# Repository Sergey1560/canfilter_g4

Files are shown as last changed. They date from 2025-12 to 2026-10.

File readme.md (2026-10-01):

# CAN Filter

[Схема платы](./canfilter_g4.pdf)

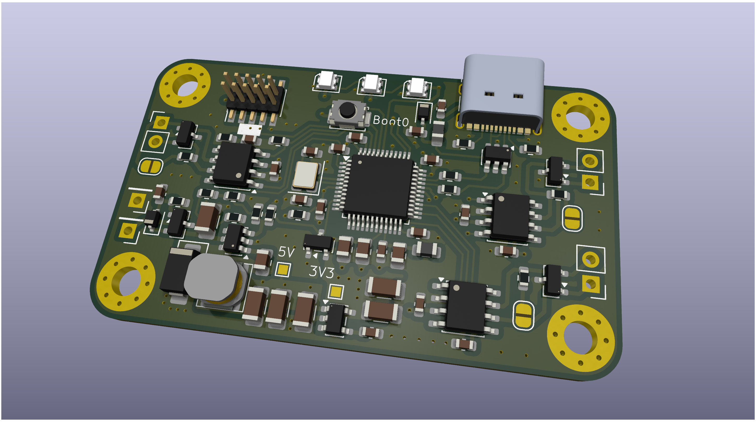
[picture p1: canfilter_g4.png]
top


# Примеры кода

- [AEM2ABIT](https://github.com/Sergey1560/canfilter_aem2abit) конвертирует сообщения от ШДК AEM в формат ADLM ABIT
- [SOCKET_CAN](https://github.com/Sergey1560/canfilter_socketcan_sw) USB адаптер для Linux с 3-мя интерфейсами CAN

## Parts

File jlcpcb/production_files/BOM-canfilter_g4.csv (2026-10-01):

Comment | Designator | Footprint | LCSC | Quantity
0.1uF | C108,C109,C111,C113,C114,C116,C301,C302,C401,C402,C501,C502,C601,C602 | C_0603_1608Metric | C14663 | 14
0.1uF | C112,C202 | C_0805_2012Metric | C49678 | 2
100K | R104,R106,R201 | R_0603_1608Metric | C25803 | 3
10K | R101,R102,R105,R203 | R_0603_1608Metric | C25804 | 4
10nF | C102,C103 | C_0603_1608Metric | C57112 | 2
10uF | C101,C104,C107,C201,C203,C204 | C_1206_3216Metric | C13585 | 6
120 | R301,R401,R501 | R_0603_1608Metric | C22787 | 3
12pF | C105,C106 | C_0603_1608Metric | C38523 | 2
1N4148WS | D107 | D_SOD-323 | C2128 | 1
1uF | C110,C115 | C_0805_2012Metric | C28323 | 2
22uH | L201 | FNR5040S220MT | C167971 | 1
27 | R603,R604 | R_0603_1608Metric | C25190 | 2
2K | R103 | R_0603_1608Metric | C22975 | 1
5.1K | R601,R602 | R_0603_1608Metric | C23186 | 2
54.9K | R202 | R_0603_1608Metric | C728593 | 1
8Mhz | Y101 | Crystal_SMD_3225-4Pin_3.2x2.5mm | C2682775 | 1
AO3401A | Q101 | SOT-23 | C15127 | 1
BAT54S | D105 | SOT-23 | C83935 | 1
BLM21BD471SN1D | L101 | L_0805_2012Metric | C2844596 | 1
BLM21PG221SN1D | FB601 | L_0805_2012Metric | C85840 | 1
BOOT0 | SW101 | SW_Push_SPST_NO_Alps_SKRK | C115357 | 1
BZT52C16S | D101 | D_SOD-323 | C19077449 | 1
LMR16006Y | U201 | SOT-23-6 | C290195 | 1
LP2985-3.3 | U101 | SOT-23-5 | C95414 | 1
NUP2105L | D301,D401,D501 | SOT-23 | C14486 | 3
SS14FL | D202 | D_SMA | C111580 | 1
STM32G474CBTx | U102 | LQFP-48_7x7mm_P0.5mm | C730123 | 1
SWD | J106 | PinHeader_2x05_P1.27mm_Vertical_SMD | C42372555 | 1
TJA1051T-3 | U301,U401,U501 | SOIC-8_3.9x4.9mm_P1.27mm | C3234095 | 3
USBLC6-2SC6 | U601 | SOT-23-6 | C7519 | 1
USB_C_Receptacle_USB2.0 | J601 | USB_C_Receptacle_XKB_U262-16XN-4BVC11 | C319148 | 1
WS2812B-2020 | D102,D104,D106 | LED_WS2812B-2020_PLCC4_2.0x2.0mm | C965555 | 3

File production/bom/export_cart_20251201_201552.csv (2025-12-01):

Index | LCSC# | MPN | Manufacturer | Package | Customer # | Description | RoHS | Quantity | MOQ | Multiple | Unit Price($) | Extended Price($) | Product Link
1 | C42372555 | HX JN1.27-2x5 TP H4.9 | hanxia | SMD,P=1.27mm | 34 | 1.27mm -40℃~+105℃ 1A Gold Copper 500V 2x5P 5 2 IDC Header 1.27mm Surface Mount,Vertical SMD,P=1.27mm Free Hanging, Panel Mount RoHS | yes | 10 | 5 | 5 | 0.2072 | 2.07 | https://www.lcsc.com/product-detail/C42372555.html
2 | C41376037 | HX PZ1.27-2x5P TP | hanxia | SMD,P=1.27mm | 34 | 10P 2x5P Gold Brass -40℃~+105℃ Pin Header Black 1.27mm 1mm 4mm 500V 2 1A Surface Mount,Vertical 1.27mm SMD,P=1.27mm Headers, Male Pins RoHS | yes | 10 | 5 | 5 | 0.0831 | 0.83 | https://www.lcsc.com/product-detail/C41376037.html
3 | C730123 | STM32G474CBT6 | ST | LQFP-48(7x7) | 24 | ARM Cortex-M4F 170MHz 38 LQFP-48(7x7) Microcontrollers RoHS | yes | 10 | 1 | 1 | 3.4997 | 35.00 | https://www.lcsc.com/product-detail/C730123.html
4 | C14663 | CC0603KRX7R9BB104 | YAGEO | 0603 | 1 | 50V 100nF X7R ±10% 0603 Ceramic Capacitors RoHS | yes | 200 | 100 | 100 | 0.0025 | 0.50 | https://www.lcsc.com/product-detail/C14663.html
5 | C89632 | CL31B106KBHNNNE | Samsung Electro-Mechanics | 1206 | 2 | 50V 10uF X7R ±10% 1206 Ceramic Capacitors RoHS | yes | 60 | 10 | 10 | 0.0557 | 3.34 | https://www.lcsc.com/product-detail/C89632.html
6 | C100042 | CC0603KRX7R9BB103 | YAGEO | 0603 | 3 | 50V 10nF X7R ±10% 0603 Ceramic Capacitors RoHS | yes | 100 | 100 | 100 | 0.0022 | 0.22 | https://www.lcsc.com/product-detail/C100042.html
7 | C38523 | CL10C120JB8NNNC | Samsung Electro-Mechanics | 0603 | 4 | 50V 12pF C0G ±5% 0603 Ceramic Capacitors RoHS | yes | 100 | 100 | 100 | 0.0049 | 0.49 | https://www.lcsc.com/product-detail/C38523.html
8 | C77083 | GRM21BR71H105KA12L | muRata | 0805 | 5 | 50V 1uF X7R ±10% 0805 Ceramic Capacitors RoHS | yes | 20 | 20 | 20 | 0.0366 | 0.73 | https://www.lcsc.com/product-detail/C77083.html
9 | C49678 | CC0805KRX7R9BB104 | YAGEO | 0805 | 6 | 50V 100nF X7R ±10% 0805 Ceramic Capacitors RoHS | yes | 100 | 100 | 100 | 0.0045 | 0.45 | https://www.lcsc.com/product-detail/C49678.html
10 | C319148 | U262-161N-4BVC11 | XKB Connection | SMD |  | 1 16P -40℃~+85℃ Type-C SMD USB, DVI, HDMI Connector Assemblies RoHS | yes | 15 | 5 | 5 | 0.3204 | 4.81 | https://www.lcsc.com/product-detail/C319148.html
11 | C98220 | RC0603FR-0710KL | YAGEO | 0603 | 7 | 100mW 10kΩ 75V ±100ppm/℃ Thick Film Resistor ±1% 0603 Chip Resistor - Surface Mount RoHS | yes | 100 | 100 | 100 | 0.0011 | 0.11 | https://www.lcsc.com/product-detail/C98220.html
12 | C14675 | RC0603FR-07100KL | YAGEO | 0603 | 8 | 100mW 100kΩ 75V ±100ppm/℃ Thick Film Resistor ±1% 0603 Chip Resistor - Surface Mount RoHS | yes | 100 | 100 | 100 | 0.0010 | 0.10 | https://www.lcsc.com/product-detail/C14675.html
13 | C22787 | 0603WAF1200T5E | UNI-ROYAL | 0603 | 9 | 100mW 120Ω 75V ±100ppm/℃ Thick Film Resistor ±1% 0603 Chip Resistor - Surface Mount RoHS | yes | 100 | 100 | 100 | 0.0012 | 0.12 | https://www.lcsc.com/product-detail/C22787.html
14 | C2907044 | FRC0603F5101TS | FOJAN | 0603 | 10 | 100mW 5.1kΩ 75V ±100ppm/℃ Thick Film Resistor ±1% 0603 Chip Resistor - Surface Mount RoHS | yes | 100 | 100 | 100 | 0.0009 | 0.09 | https://www.lcsc.com/product-detail/C2907044.html
15 | C25190 | 0603WAF270JT5E | UNI-ROYAL | 0603 | 11 | 100mW 27Ω 75V ±200ppm/℃ Thick Film Resistor ±1% 0603 Chip Resistor - Surface Mount RoHS | yes | 100 | 100 | 100 | 0.0012 | 0.12 | https://www.lcsc.com/product-detail/C25190.html
16 | C22975 | 0603WAF2001T5E | UNI-ROYAL | 0603 | 12 | 100mW 2kΩ 75V ±100ppm/℃ Thick Film Resistor ±1% 0603 Chip Resistor - Surface Mount RoHS | yes | 100 | 100 | 100 | 0.0011 | 0.11 | https://www.lcsc.com/product-detail/C22975.html
17 | C2999457 | FRC0603F5492TS | FOJAN | 0603 | 13 | 100mW 54.9kΩ 75V ±100ppm/℃ Thick Film Resistor ±1% 0603 Chip Resistor - Surface Mount RoHS | yes | 100 | 100 | 100 | 0.0009 | 0.09 | https://www.lcsc.com/product-detail/C2999457.html
18 | C710507 | BLM21BD471SN1D | muRata | 0805 | 14 | 350mΩ ±25% 470Ω@100MHz 0805 Ferrite Beads and Chips RoHS | yes | 20 | 10 | 10 | 0.0571 | 1.14 | https://www.lcsc.com/product-detail/C710507.html
19 | C167971 | FNR5040S220MT | cjiang | SMD,5x5mm | 15 | 22uH Magnetic Shielded Inductor 1.8A SMD,5x5mm Fixed Inductors RoHS | yes | 20 | 10 | 10 | 0.0933 | 1.87 | https://www.lcsc.com/product-detail/C167971.html
20 | C965555 | WS2812B-2020 | Worldsemi | SMD,2.2x2mm | 16 | SMD,2.2x2mm LED Addressable, Specialty RoHS | yes | 50 | 5 | 5 | 0.0658 | 3.29 | https://www.lcsc.com/product-detail/C965555.html
21 | C284104 | NUP2105L | DOWO | SOT-23 | 17 | 8A 420W@8/20us 43V 26.7V Bidirectional 24V SOT-23 TVS Diodes RoHS | yes | 30 | 10 | 10 | 0.0478 | 1.43 | https://www.lcsc.com/product-detail/C284104.html
22 | C19077449 | BZT52C16S | R+O | SOD-323 | 18 | Independent 200mW 15.3V~17.1V 16V SOD-323 Single Zener Diodes RoHS | yes | 50 | 50 | 50 | 0.0155 | 0.78 | https://www.lcsc.com/product-detail/C19077449.html
23 | C47546 | BAT54S,215 | Nexperia | SOT-23 | 19 | 600mA 1 Pair Series Connection 30V 800mV@100mA 200mA SOT-23 Single Diodes RoHS | yes | 30 | 5 | 5 | 0.0883 | 2.65 | https://www.lcsc.com/product-detail/C47546.html
24 | C118873 | 1N4148WS | onsemi | SOD-323 | 20 | 4ns 75V Independent 1V@10mA 150mA SOD-323 Single Diodes RoHS | yes | 20 | 20 | 20 | 0.0378 | 0.76 | https://www.lcsc.com/product-detail/C118873.html
25 | C111580 | SS14FL | Shikues | SMAF | 21 | 40A Independent 40V 450mV@1A 1A SMAF Single Diodes RoHS | yes | 20 | 20 | 20 | 0.0409 | 0.82 | https://www.lcsc.com/product-detail/C111580.html
26 | C38695 | TJA1051T/3/1J | NXP | SOIC-8-150mil | 22 | CAN FD Transceiver 110mA 4.5V~5.5V SOIC-8-150mil Drivers, Receivers, Transceivers RoHS | yes | 30 | 5 | 5 | 0.5013 | 15.04 | https://www.lcsc.com/product-detail/C38695.html
27 | C95414 | LP2985-33DBVR | TI | SOT-23-5 | 23 | 45dB@(1kHz) Positive Fixed 3.3V SOT-23-5 Voltage Regulators - Linear, Low Drop Out (LDO) Regulators RoHS | yes | 10 | 5 | 5 | 0.1110 | 1.11 | https://www.lcsc.com/product-detail/C95414.html
28 | C290195 | LMR16006YDDCR | TI | SOT-23-6 | 25 | 2.1MHz Buck Adjustable 1 SOT-23-6 Voltage Regulators - DC DC Switching Regulators RoHS | yes | 10 | 1 | 1 | 0.3978 | 3.98 | https://www.lcsc.com/product-detail/C290195.html
29 | C7519 | USBLC6-2SC6 | ST | SOT-23-6L | 26 | 5A 17V 6V Unidirectional 5.25V SOT-23-6L TVS Diodes RoHS | yes | 10 | 5 | 5 | 0.1035 | 1.04 | https://www.lcsc.com/product-detail/C7519.html
30 | C2682775 | X32258MOB4SI | YXC Crystal Oscillators | SMD3225-4P | 27 | Crystal Oscillator 12pF SMD3225-4P Crystals RoHS | yes | 10 | 5 | 5 | 0.1583 | 1.58 | https://www.lcsc.com/product-detail/C2682775.html
31 | C115357 | SKRKAEE020 | ALPSALPINE | SMD,3.9x2.9mm | 28 | 12V 2.9mm Round Button 3.9mm SPST 50mA SMD,3.9x2.9mm Tactile Switches RoHS | yes | 10 | 5 | 5 | 0.1277 | 1.28 | https://www.lcsc.com/product-detail/C115357.html
32 | C85840 | BLM21PG221SN1D | muRata | 0805 |  | 45mΩ ±25% 220Ω@100MHz 0805 Ferrite Beads and Chips RoHS | yes | 50 | 50 | 50 | 0.0162 | 0.81 | https://www.lcsc.com/product-detail/C85840.html
33 | C347476 | AO3401A | UMW | SOT-23 |  | 30V 4.2A 50mΩ@10V 1.4W 1 P-Channel SOT-23 Single FETs, MOSFETs RoHS | yes | 20 | 20 | 20 | 0.0310 | 0.62 | https://www.lcsc.com/product-detail/C347476.html

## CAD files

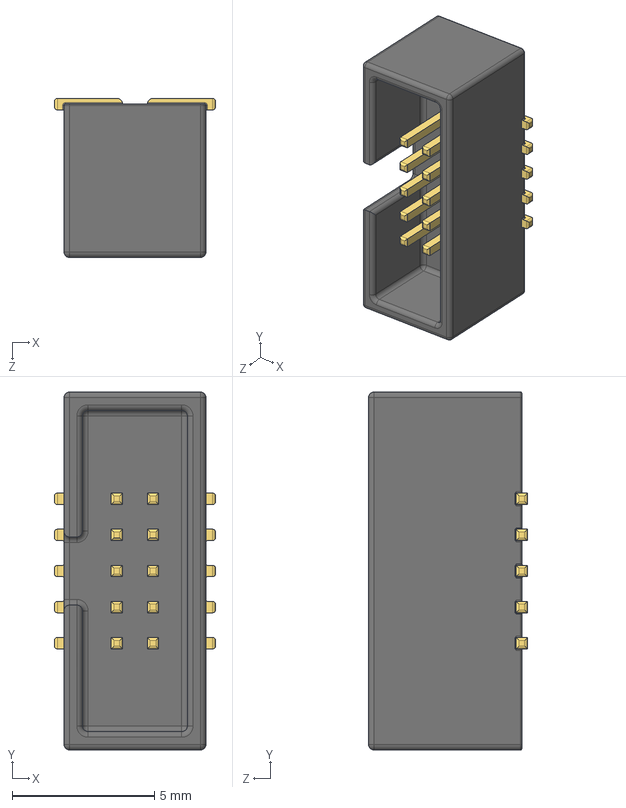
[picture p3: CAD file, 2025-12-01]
3d/IDC2x05_SMD.STEP
5.67 x 12.6 x 5.60 mm

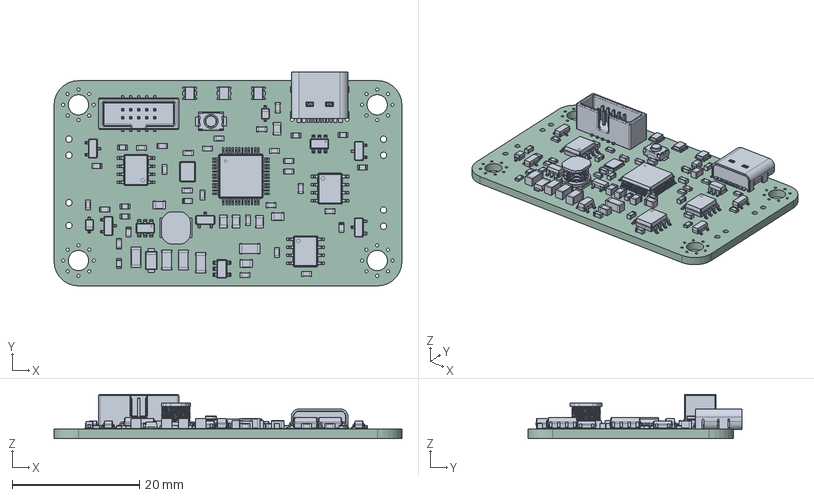
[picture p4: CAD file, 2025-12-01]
canfilter_g4.step
54.8 x 33.6 x 7.00 mm
R_0603_1608Metric x 16
fnr5040s
C_0603_1608Metric x 18
C_1206_3216Metric x 5
SW_Push_SPST_NO_Alps_SKRK
C_0805_2012Metric x 5
L_0805_2012Metric x 2
IDC2x05_SMD
D_SOD-323 x 2
LQFP-48_7x7mm_P0.5mm
SOT-23-6 x 2
Crystal_SMD_3225-4Pin_3.2x2.5mm
SOIC-8_3.9x4.9mm_P1.27mm x 3
USB Type C Port (SMD Type)
Led_WS2812B_2020 x 3
SOT-23-5
SOT-23 x 5
D_SMF
canfilter_g4_PCB

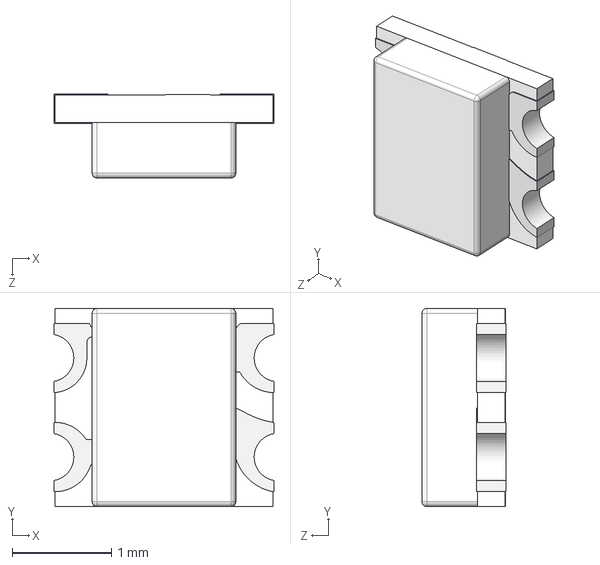
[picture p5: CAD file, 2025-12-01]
3d/Led_WS2812B_2020.STEP
2.22 x 2.00 x 0.85 mm

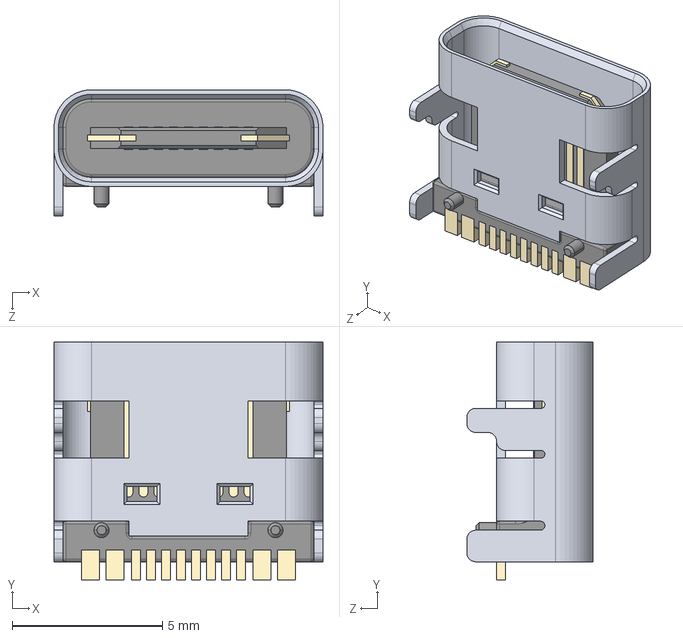
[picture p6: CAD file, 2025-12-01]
3d/USB Type C Port (SMD Type).STEP
8.94 x 7.90 x 4.20 mm

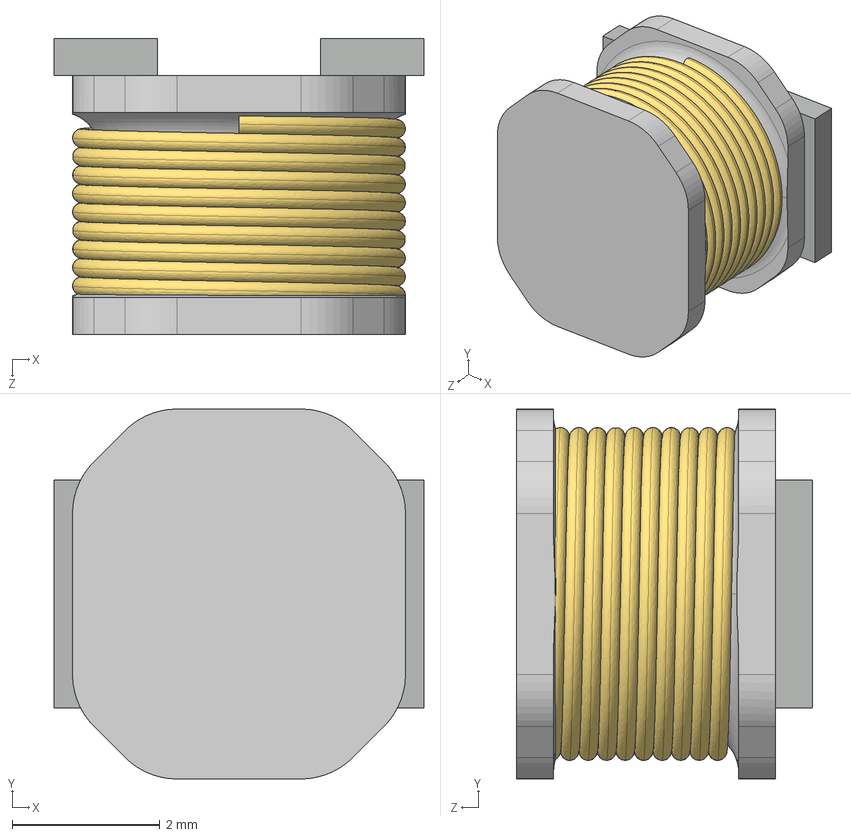
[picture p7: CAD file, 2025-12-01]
3d/fnr5040s.STEP
5.00 x 5.00 x 4.00 mm

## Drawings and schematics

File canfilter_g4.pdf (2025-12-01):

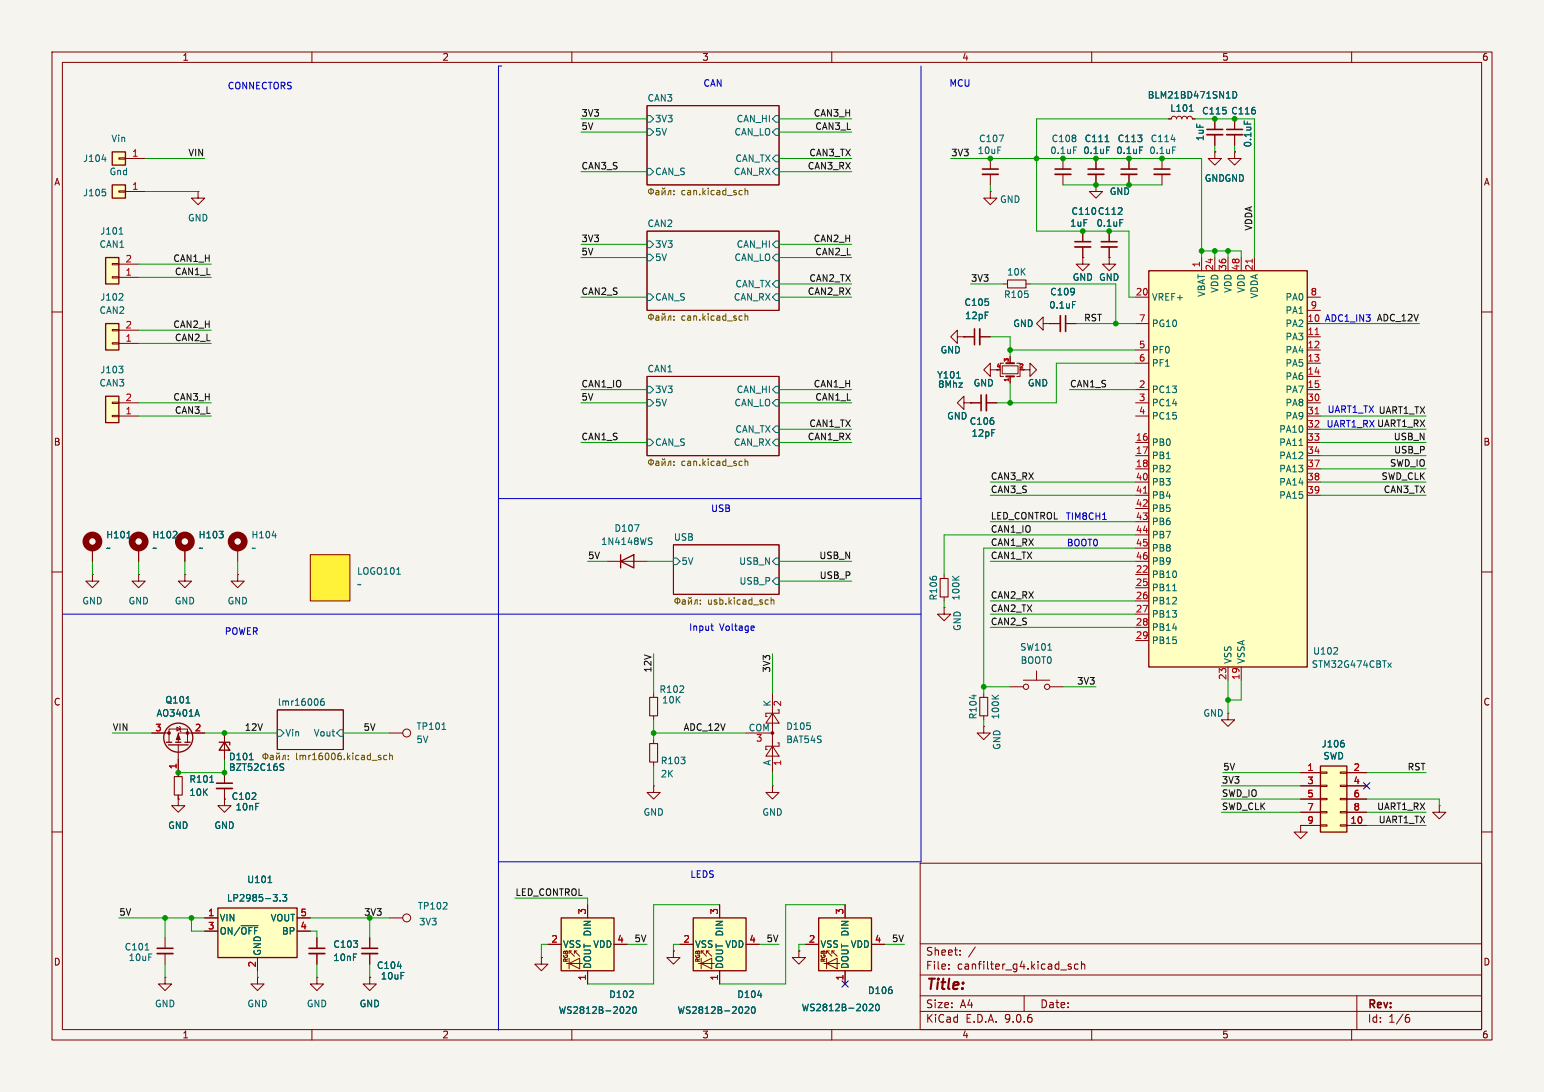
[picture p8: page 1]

1 VDD 24 VDD 36 VSS 23 VDD 48 VSSA 19 VDDA 21 PA0 8 PA1 9 PA2 10 PA3 11 PA4 12 PA5 13 PA6 14 PA7 15 PA8 30 PA9 31 PA10 32 PA11 33 PA12 34 PA13 37 PA14 38 PA15 39U102 STM32G474CBTx GND

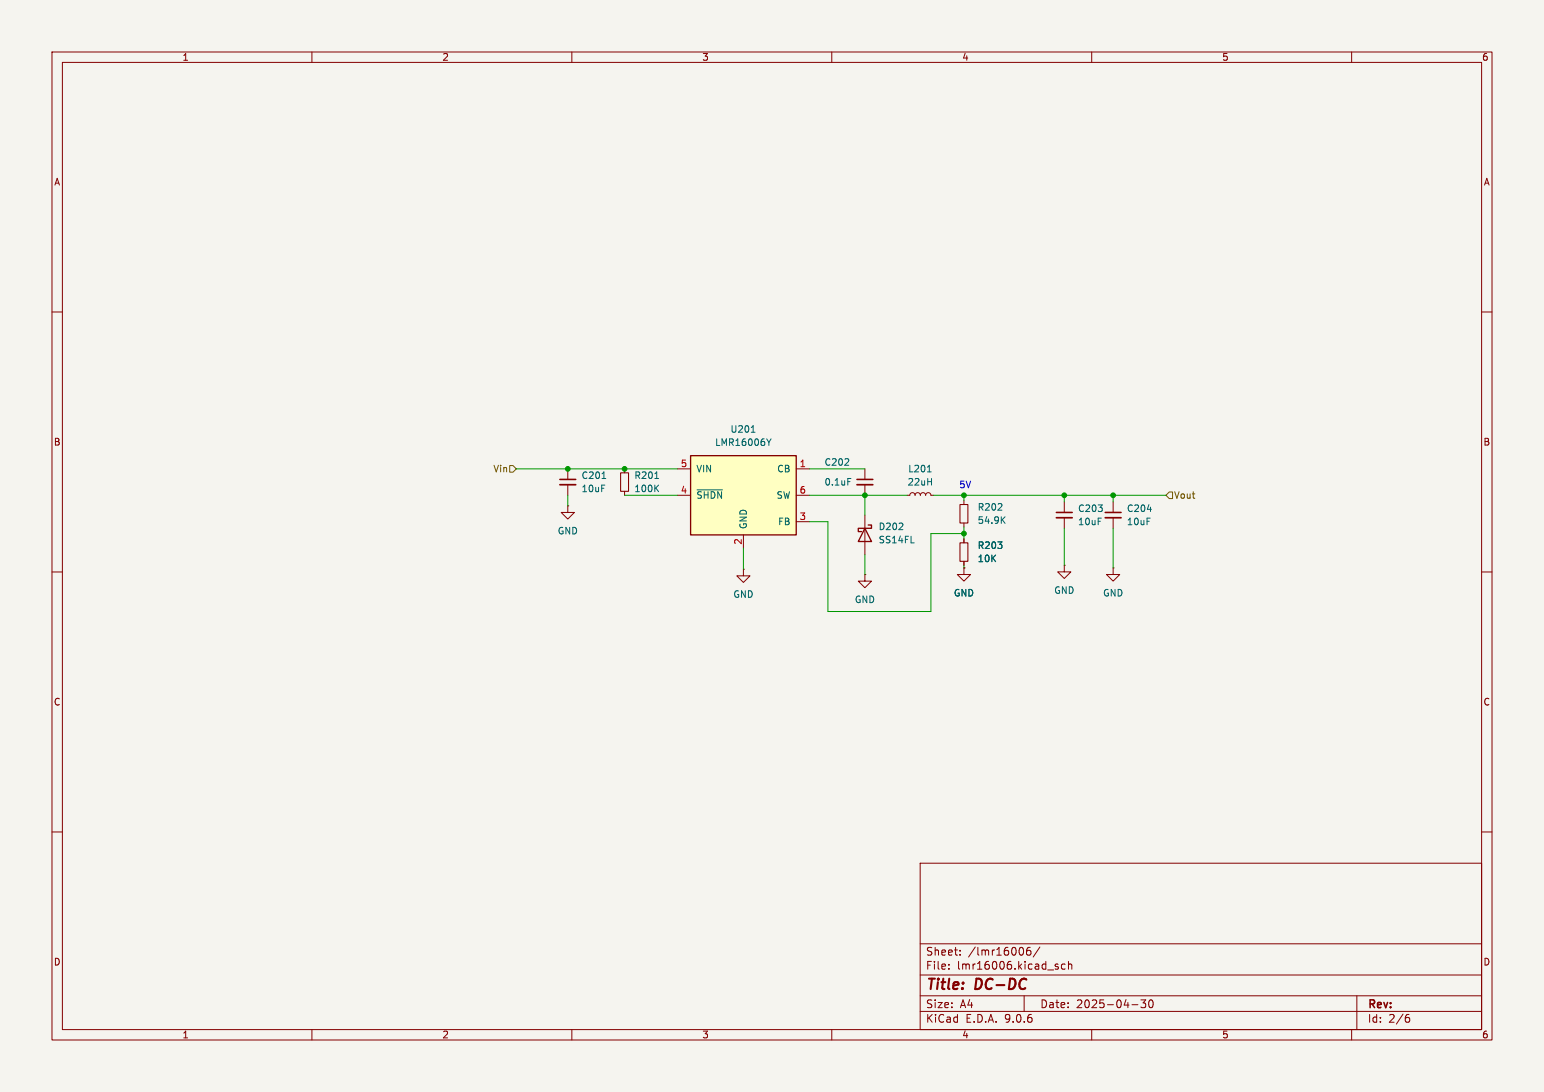
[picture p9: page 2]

File: lmr16006.kicad_sch Sheet: /lmr16006/
Id: 2/6 Title: DC-DC

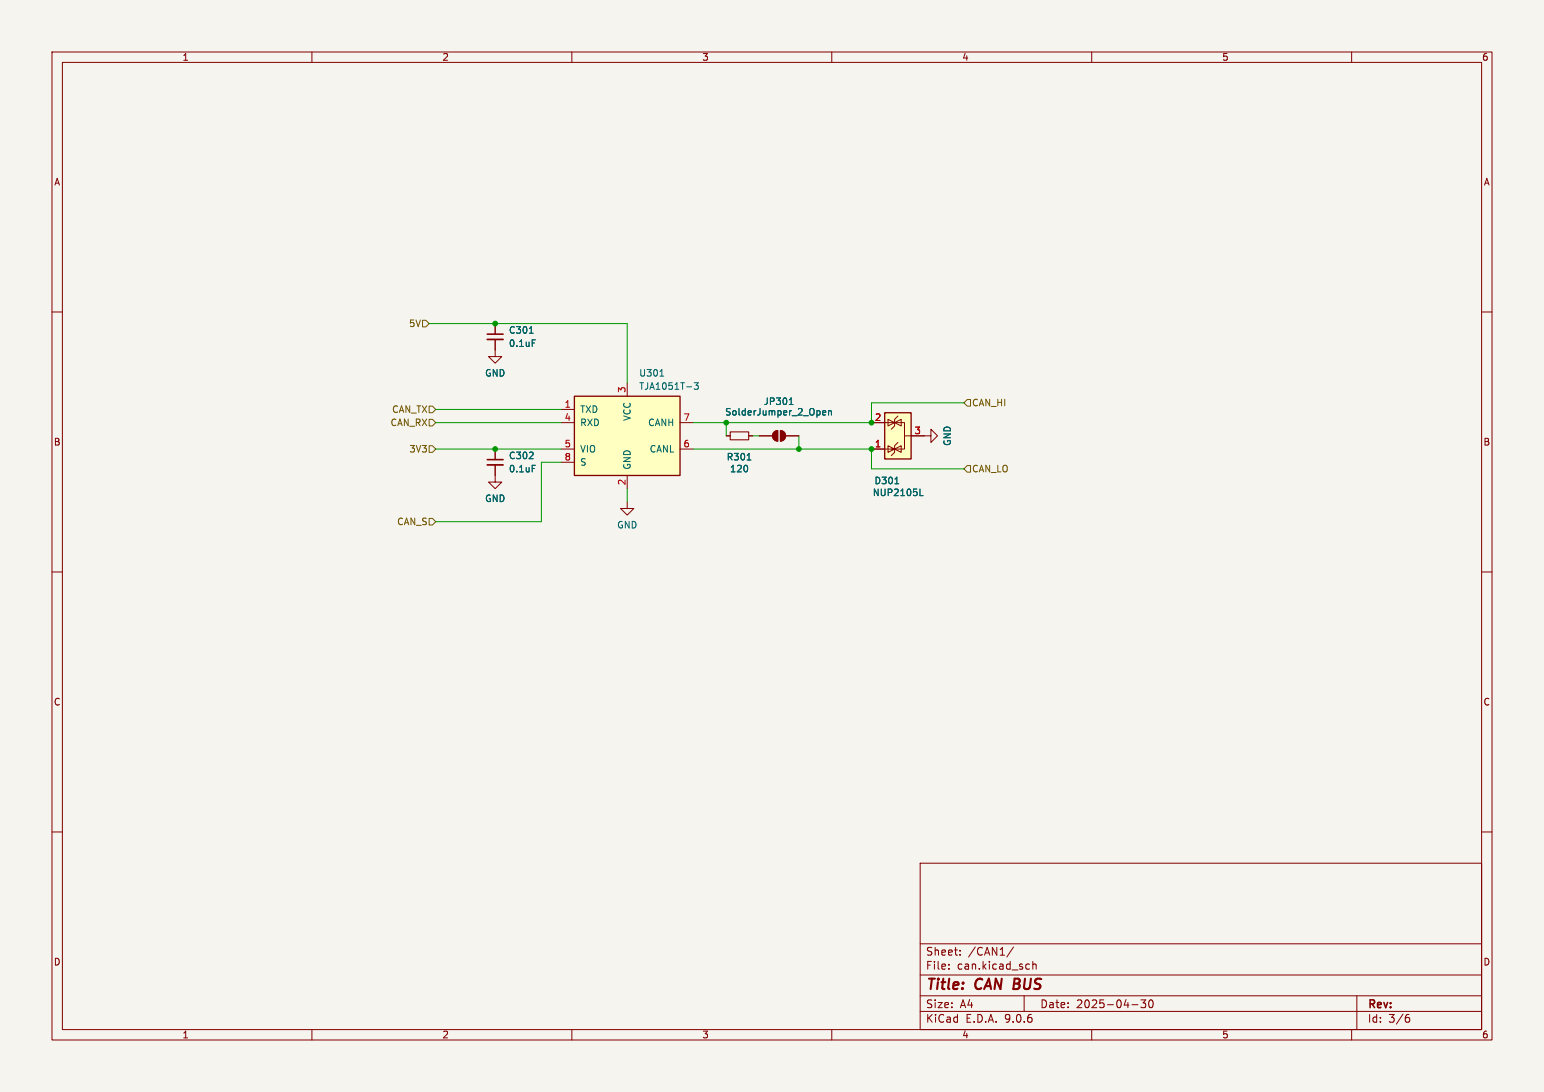
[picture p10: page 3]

File: can.kicad_sch Sheet: /CAN1/
Id: 3/6 Title: CAN BUS

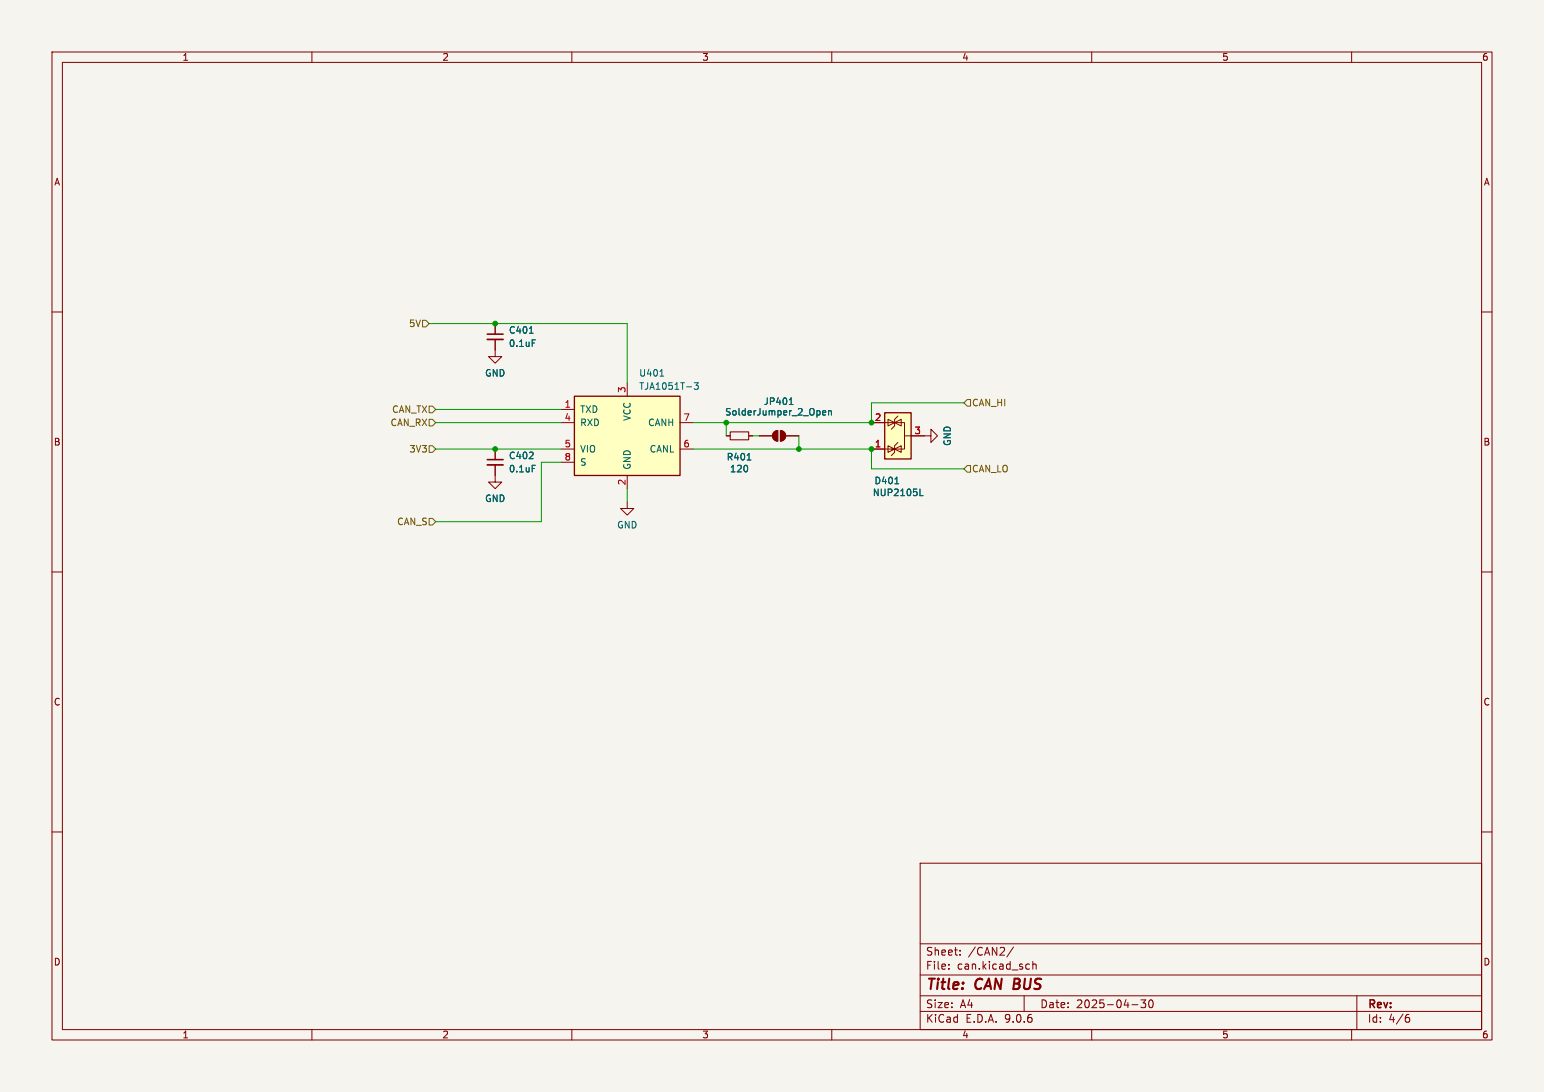
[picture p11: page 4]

File: can.kicad_sch Sheet: /CAN2/
Id: 4/6 Title: CAN BUS

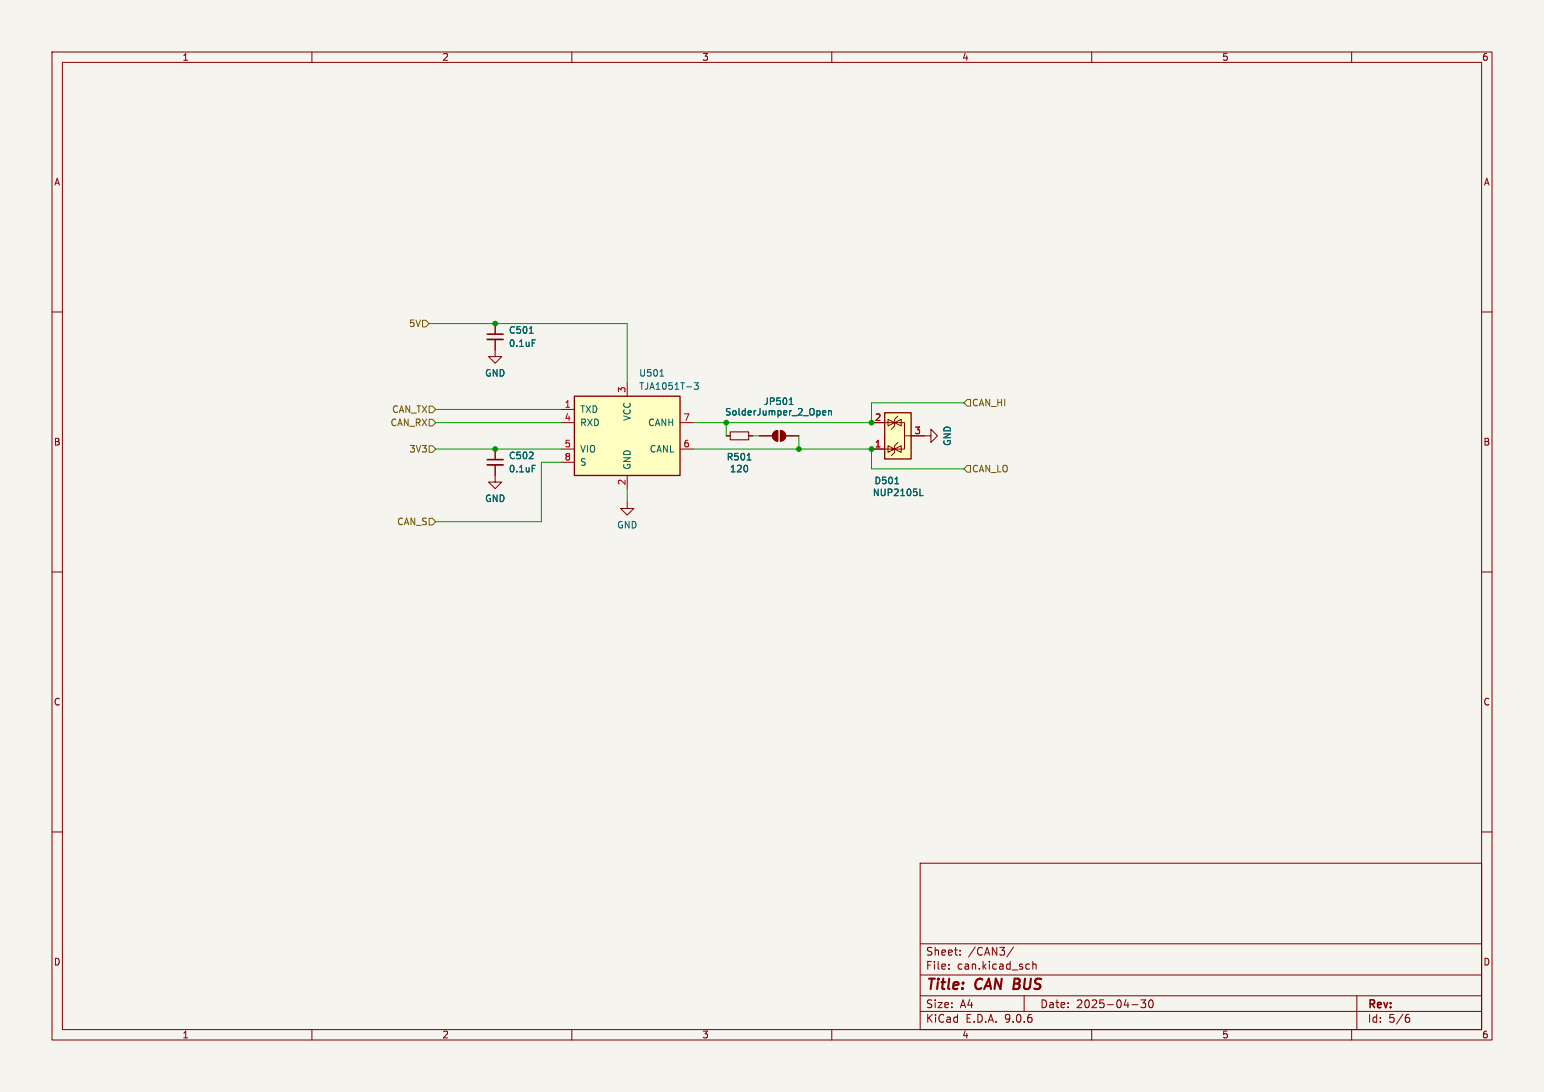
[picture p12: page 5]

File: can.kicad_sch Sheet: /CAN3/
Id: 5/6 Title: CAN BUS

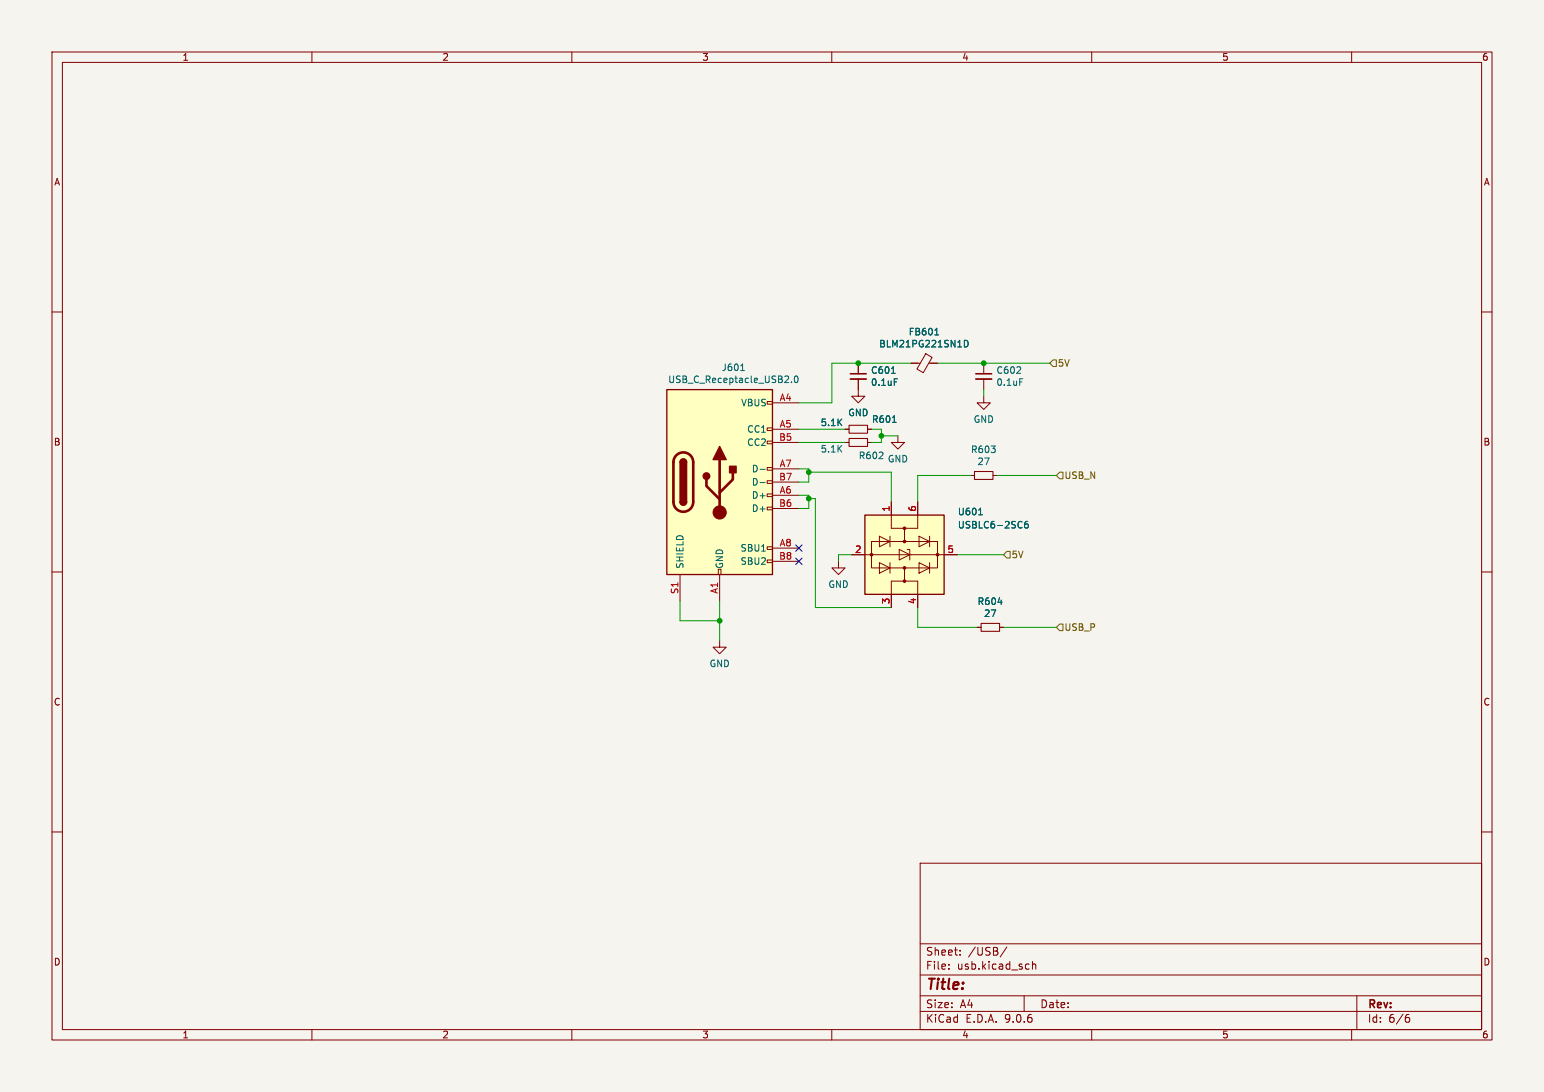
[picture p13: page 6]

Id: 6/6 Title: File: usb.kicad_sch Sheet: /USB/

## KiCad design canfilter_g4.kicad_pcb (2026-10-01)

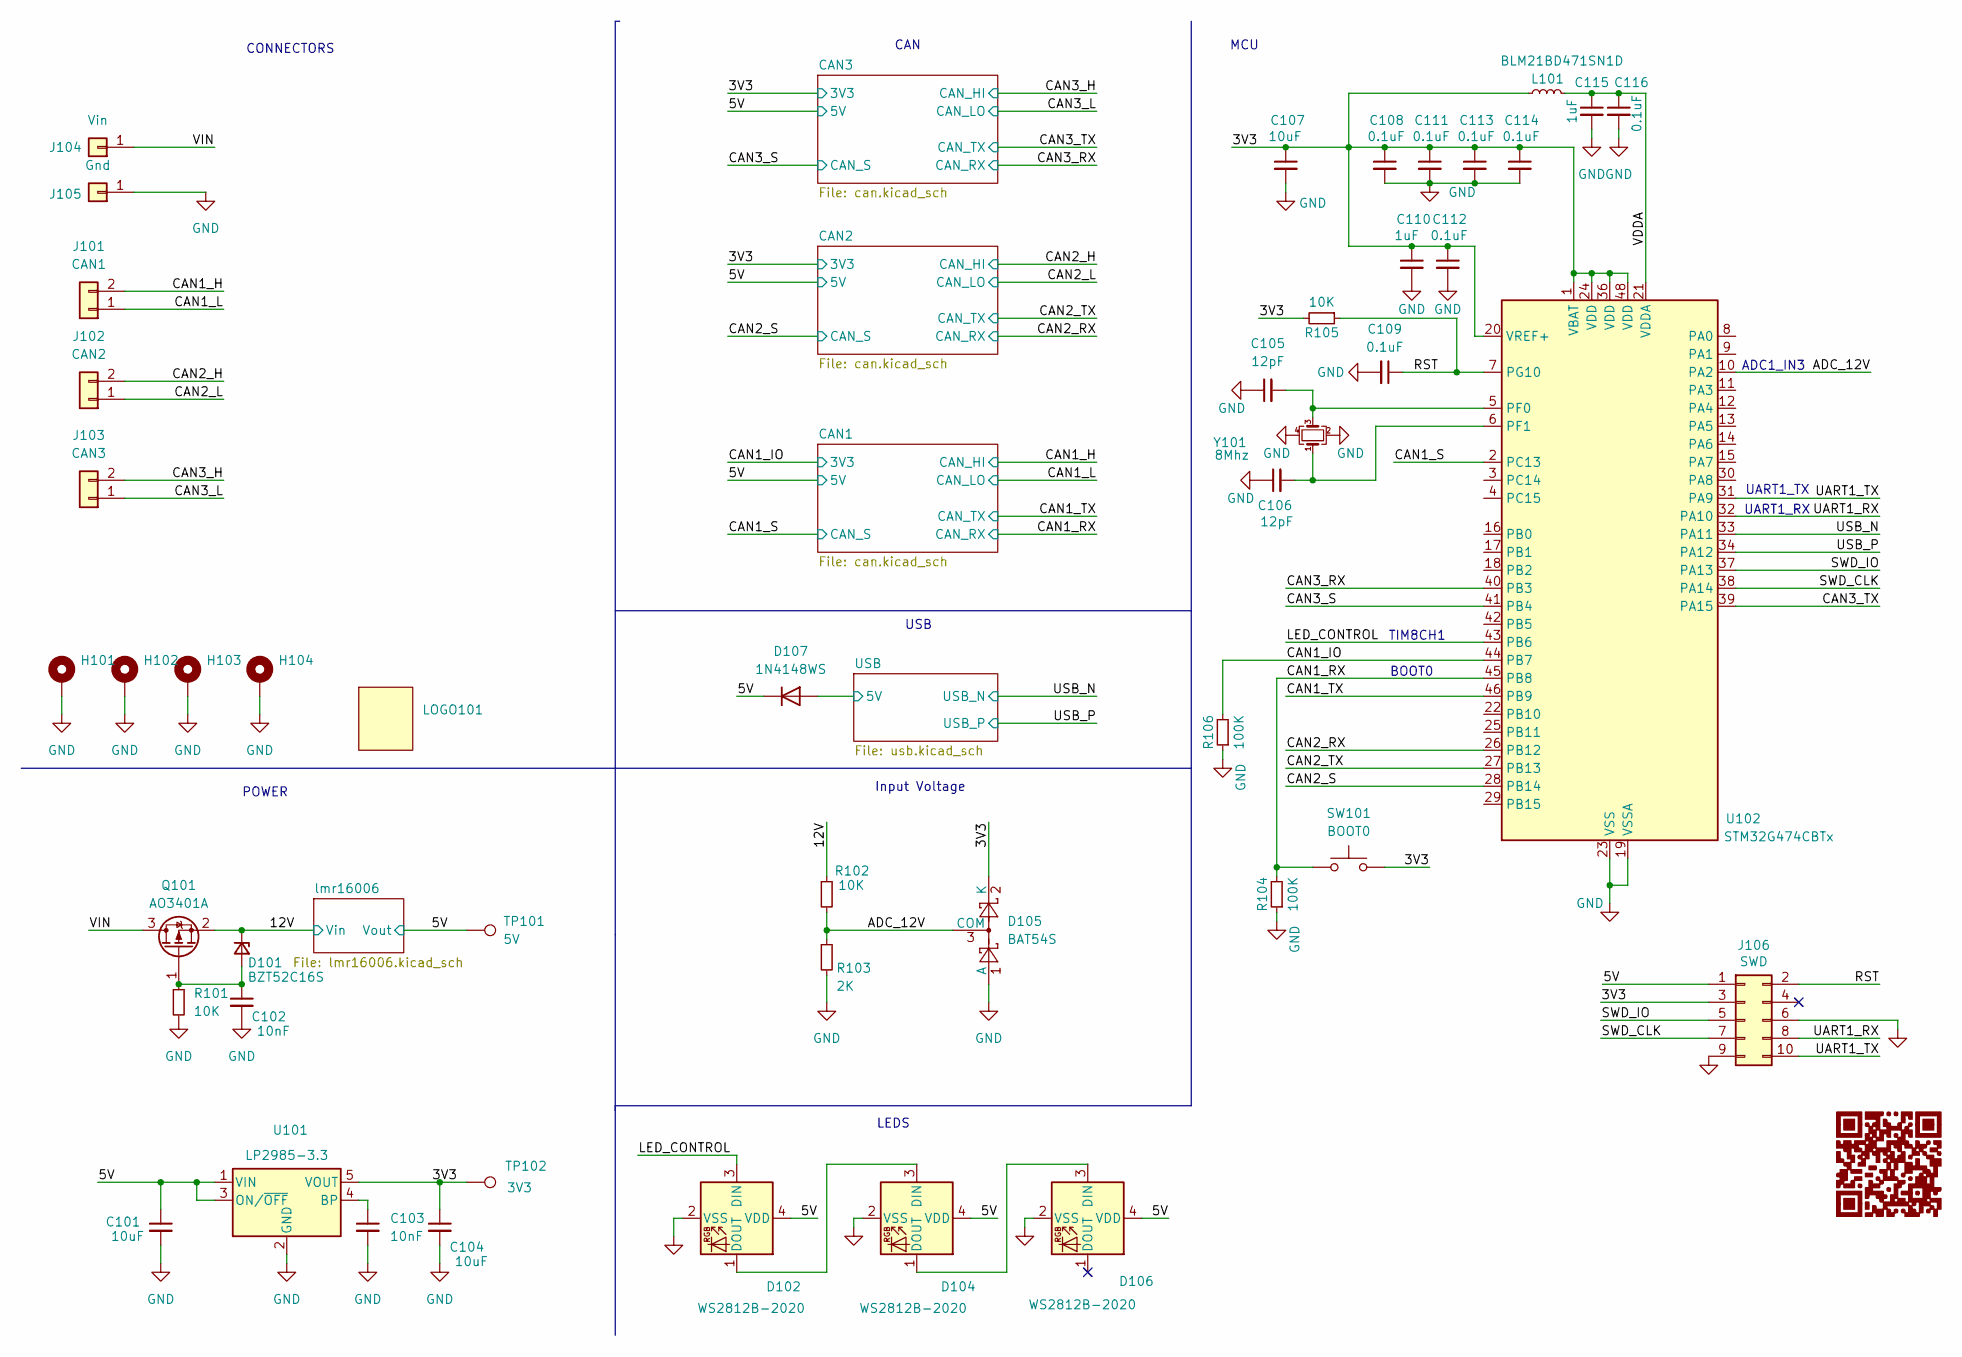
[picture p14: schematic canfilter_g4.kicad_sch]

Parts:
C101: 10uF; C_1206_3216Metric; LCSC C91186
C102, C103: 10nF; C_0603_1608Metric; LCSC C100042
C104: 10uF; C_1206_3216Metric; LCSC C162273
C105, C106: 12pF; C_0603_1608Metric; LCSC C519482
C107: 10uF; C_1206_3216Metric; LCSC C91606
C108, C109, C111, C113, C114, C116: 0.1uF; C_0603_1608Metric; LCSC C92490
C110: 1uF; C_0805_2012Metric; LCSC C91186
C112: 0.1uF; C_0805_2012Metric; LCSC C92490
C115: 1uF; C_0805_2012Metric; LCSC C91185
D101: BZT52C16S; D_SOD-323; LCSC C19077449
D102, D104, D106: WS2812B-2020; LED_WS2812B-2020_PLCC4_2.0x2.0mm; LCSC C965555
D105: BAT54S; SOT-23; LCSC C5805802
D107: 1N4148WS; D_SOD-323
H101, H102, H103, H104: MountingHole_3.2mm_M3_Pad_Via
J101: CAN1; PinHeader_1x02_P2.54mm_Vertical
J102: CAN2; PinHeader_1x02_P2.54mm_Vertical
J103: CAN3; PinHeader_1x02_P2.54mm_Vertical
J104: Vin; PinHeader_1x01_P2.54mm_Vertical
J105: Gnd; PinHeader_1x01_P2.54mm_Vertical
J106: SWD; PinHeader_2x05_P1.27mm_Vertical_SMD; LCSC C42372555
L101: BLM21BD471SN1D; L_0805_2012Metric; LCSC C710507
LOGO101: logo_15x9
Q101: AO3401A; SOT-23; LCSC C347476
R101, R102, R105: 10K; R_0603_1608Metric; LCSC C98220
R103: 2K; R_0603_1608Metric; LCSC C125933
R104, R106: 100K; R_0603_1608Metric; LCSC C98220
SW101: BOOT0; SW_Push_SPST_NO_Alps_SKRK
TP101: 5V; TestPoint_Pad_1.0x1.0mm
TP102: 3V3; TestPoint_Pad_1.0x1.0mm
U101: LP2985-3.3; SOT-23-5; LCSC C95414
U102: STM32G474CBTx; LQFP-48_7x7mm_P0.5mm; LCSC C730123
Y101: 8Mhz; Crystal_SMD_3225-4Pin_3.2x2.5mm; LCSC C2682775

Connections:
/3V3: C104.1, C107.1, C108.1, C110.1, C111.1, C112.1, C113.1, C114.1, D105.2 (K), J106.3, L101.1, R105.2, SW101.2, TP102.1, U101.5 (VOUT), U102.1 (VBAT), U102.20 (VREF+), U102.24 (VDD), U102.36 (VDD), U102.48 (VDD); also elsewhere on the board
/5V: C101.1, D102.4 (VDD), D104.4 (VDD), D106.4 (VDD), D107.1 (K), J106.1, TP101.1, U101.1 (VIN), U101.3 (ON/~OFF); also elsewhere on the board
/12V: D101.1 (K), Q101.2 (S), R102.1; also elsewhere on the board
/ADC_12V: D105.3 (COM), R102.2, R103.1, U102.10 (PA2)
/CAN1_H: J101.2; also elsewhere on the board
/CAN1_IO: R106.2, U102.44 (PB7); also elsewhere on the board
/CAN1_L: J101.1; also elsewhere on the board
/CAN1_RX: R104.2, SW101.1, U102.45 (PB8); also elsewhere on the board
/CAN1_S: U102.2 (PC13); also elsewhere on the board
/CAN1_TX: U102.46 (PB9); also elsewhere on the board
/CAN2_H: J102.2; also elsewhere on the board
/CAN2_L: J102.1; also elsewhere on the board
/CAN2_RX: U102.26 (PB12); also elsewhere on the board
/CAN2_S: U102.28 (PB14); also elsewhere on the board
/CAN2_TX: U102.27 (PB13); also elsewhere on the board
/CAN3_H: J103.2; also elsewhere on the board
/CAN3_L: J103.1; also elsewhere on the board
/CAN3_RX: U102.40 (PB3); also elsewhere on the board
/CAN3_S: U102.41 (PB4); also elsewhere on the board
/CAN3_TX: U102.39 (PA15); also elsewhere on the board
/LED_CONTROL: D102.3 (DIN), U102.43 (PB6)
/RST: C109.1, J106.2, R105.1, U102.7 (PG10)
/SWD_CLK: J106.7, U102.38 (PA14)
/SWD_IO: J106.5, U102.37 (PA13)
/UART1_RX: J106.8, U102.32 (PA10)
/UART1_TX: J106.10, U102.31 (PA9)
/USB/5V: D107.2 (A); also elsewhere on the board
/USB_N: U102.33 (PA11); also elsewhere on the board
/USB_P: U102.34 (PA12); also elsewhere on the board
/VDDA: C115.1, C116.1, L101.2, U102.21 (VDDA)
/VIN: J104.1, Q101.3 (D)
GND: C101.2, C102.2, C103.2, C104.2, C105.1, C106.1, C107.2, C108.2, C109.2, C110.2, C111.2, C112.2, C113.2, C114.2, C115.2, C116.2, D102.2 (VSS), D104.2 (VSS), D105.1 (A), D106.2 (VSS), H101.1, H102.1, H103.1, H104.1, J105.1, J106.6, J106.9, R101.2, R103.2, R104.1, R106.1, U101.2 (GND), U102.19 (VSSA), U102.23 (VSS), U102.35 (VSS), U102.47 (VSS), Y101.2, Y101.4; also elsewhere on the board
unnamed: C102.1, D101.2 (A), Q101.1 (G), R101.1
unnamed: D102.1 (DOUT), D104.3 (DIN)
unnamed: D104.1 (DOUT), D106.3 (DIN)
unnamed: C103.1, U101.4 (BP)
unnamed: C105.2, U102.5 (PF0), Y101.3
unnamed: C106.2, U102.6 (PF1), Y101.1

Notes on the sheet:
POWER
BOOT0
CAN
CONNECTORS
ADC1_IN3
LEDS
UART1_TX
Input Voltage
TIM8CH1
MCU
USB
UART1_RX

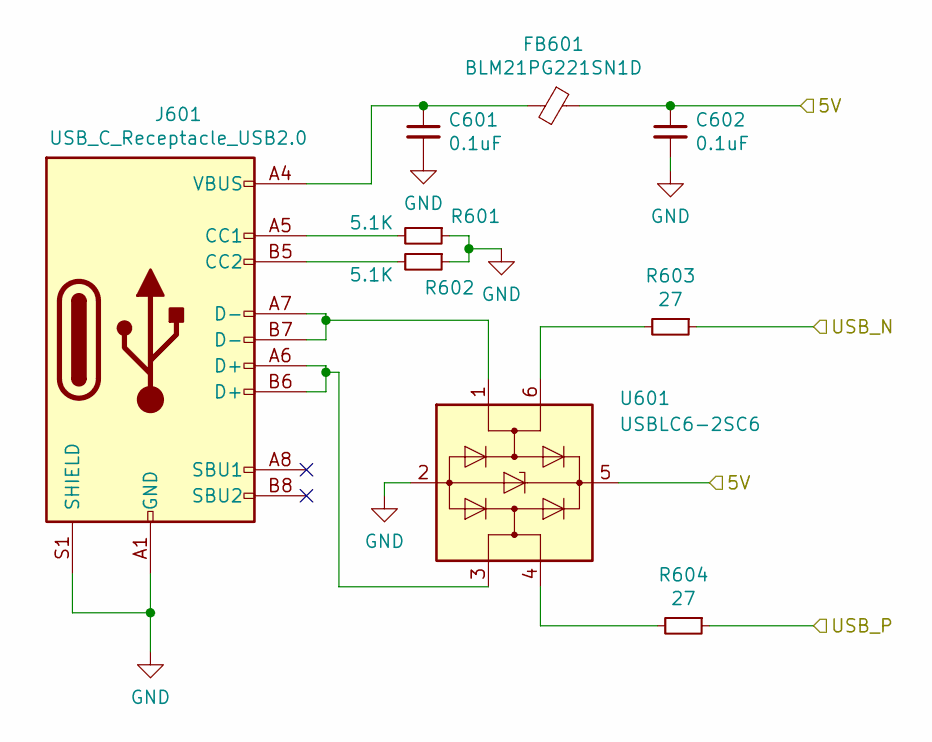
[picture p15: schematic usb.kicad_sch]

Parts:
C601, C602: 0.1uF; C_0603_1608Metric
FB601: BLM21PG221SN1D; L_0805_2012Metric
J601: USB_C_Receptacle_USB2.0; USB_C_Receptacle_XKB_U262-16XN-4BVC11
R601, R602: 5.1K; R_0603_1608Metric
R603, R604: 27; R_0603_1608Metric
U601: USBLC6-2SC6; SOT-23-6; LCSC C7519

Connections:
/USB/5V: C602.1, FB601.1, U601.5 (VBUS); also elsewhere on the board
/USB_N: R603.1; also elsewhere on the board
/USB_P: R604.1; also elsewhere on the board
GND: C601.2, C602.2, J601.A1 (GND), J601.A12 (GND), J601.B1 (GND), J601.B12 (GND), J601.S1 (SHIELD), R601.1, R602.1, U601.2 (GND); also elsewhere on the board
unnamed: C601.1, FB601.2, J601.A4 (VBUS), J601.A9 (VBUS), J601.B4 (VBUS), J601.B9 (VBUS)
unnamed: J601.A5 (CC1), R601.2
unnamed: J601.B5 (CC2), R602.2
unnamed: J601.A6 (D+), J601.B6 (D+), U601.3 (I/O2)
unnamed: J601.A7 (D-), J601.B7 (D-), U601.1 (I/O1)
unnamed: R603.2, U601.6 (I/O1)
unnamed: R604.2, U601.4 (I/O2)

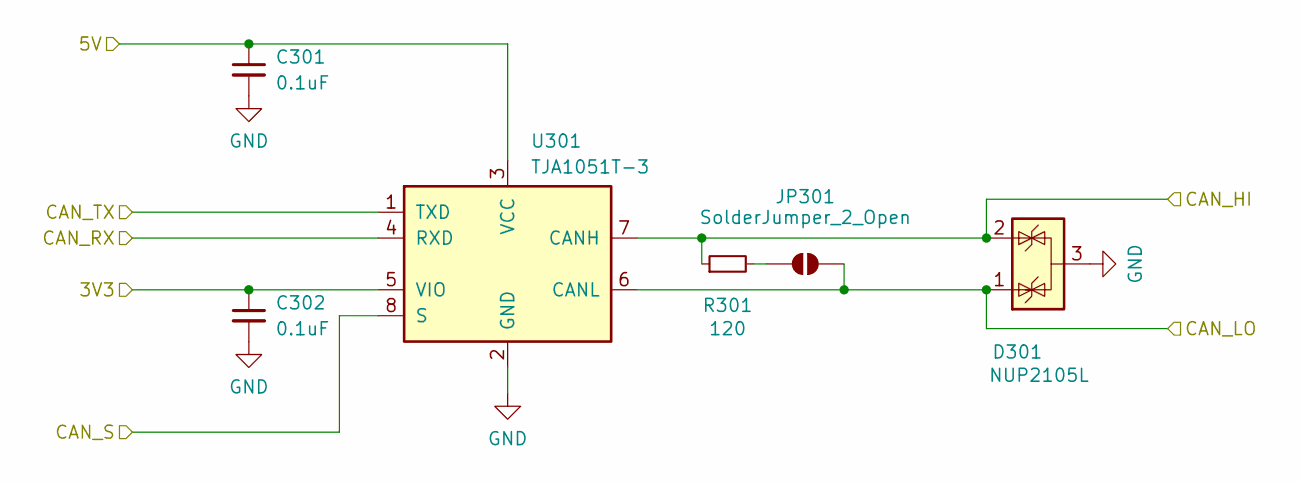
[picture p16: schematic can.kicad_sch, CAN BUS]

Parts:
C301, C302: 0.1uF; C_0603_1608Metric; LCSC C92490
D301: NUP2105L; SOT-23; LCSC C284104
JP301: SolderJumper_2_Open; SolderJumper-2_P1.3mm_Open_RoundedPad1.0x1.5mm
R301: 120; R_0603_1608Metric; LCSC C25196
U301: TJA1051T-3; SOIC-8_3.9x4.9mm_P1.27mm; LCSC C38695

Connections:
/5V: C301.1, U301.3 (VCC); also elsewhere on the board
/CAN1_H: D301.2 (K), R301.1, U301.7 (CANH); also elsewhere on the board
/CAN1_IO: C302.1, U301.5 (VIO); also elsewhere on the board
/CAN1_L: D301.1 (K), JP301.2 (B), U301.6 (CANL); also elsewhere on the board
/CAN1_RX: U301.4 (RXD); also elsewhere on the board
/CAN1_S: U301.8 (S); also elsewhere on the board
/CAN1_TX: U301.1 (TXD); also elsewhere on the board
GND: C301.2, C302.2, D301.3 (A), U301.2 (GND); also elsewhere on the board
unnamed: JP301.1 (A), R301.2

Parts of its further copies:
C401, C402, C501, C502: 0.1uF; C_0603_1608Metric; LCSC C92490
D401, D501: NUP2105L; SOT-23; LCSC C284104
JP401, JP501: SolderJumper_2_Open; SolderJumper-2_P1.3mm_Open_RoundedPad1.0x1.5mm
R401, R501: 120; R_0603_1608Metric; LCSC C25196
U401, U501: TJA1051T-3; SOIC-8_3.9x4.9mm_P1.27mm; LCSC C38695

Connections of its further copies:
/3V3: C402.1, C502.1, U401.5 (VIO), U501.5 (VIO); also elsewhere on the board
/5V: C401.1, C501.1, U401.3 (VCC), U501.3 (VCC); also elsewhere on the board
/CAN2_H: D401.2 (K), R401.1, U401.7 (CANH); also elsewhere on the board
/CAN2_L: D401.1 (K), JP401.2 (B), U401.6 (CANL); also elsewhere on the board
/CAN2_RX: U401.4 (RXD); also elsewhere on the board
/CAN2_S: U401.8 (S); also elsewhere on the board
/CAN2_TX: U401.1 (TXD); also elsewhere on the board
/CAN3_H: D501.2 (K), R501.1, U501.7 (CANH); also elsewhere on the board
/CAN3_L: D501.1 (K), JP501.2 (B), U501.6 (CANL); also elsewhere on the board
/CAN3_RX: U501.4 (RXD); also elsewhere on the board
/CAN3_S: U501.8 (S); also elsewhere on the board
/CAN3_TX: U501.1 (TXD); also elsewhere on the board
GND: C401.2, C402.2, C501.2, C502.2, D401.3 (A), D501.3 (A), U401.2 (GND), U501.2 (GND); also elsewhere on the board
unnamed: JP401.1 (A), R401.2
unnamed: JP501.1 (A), R501.2

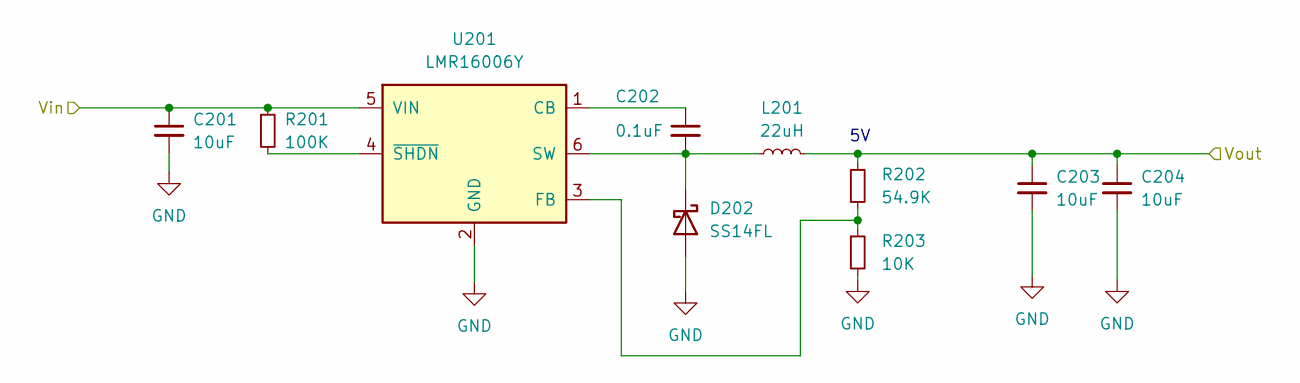
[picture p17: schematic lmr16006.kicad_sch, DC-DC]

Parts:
C201, C203, C204: 10uF; C_1206_3216Metric; LCSC C440198
C202: 0.1uF; C_0805_2012Metric; LCSC C14663
D202: SS14FL; D_SMA
L201: 22uH; FNR5040S220MT; LCSC C167971
R201: 100K; R_0603_1608Metric; LCSC C163504
R202: 54.9K; R_0603_1608Metric; LCSC C728593
R203: 10K; R_0603_1608Metric; LCSC C98220
U201: LMR16006Y; SOT-23-6; LCSC C290195

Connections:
/5V: C203.1, C204.1, L201.2, R202.1; also elsewhere on the board
/12V: C201.1, R201.1, U201.5 (VIN); also elsewhere on the board
GND: C201.2, C203.2, C204.2, D202.2 (A), R203.2, U201.2 (GND); also elsewhere on the board
unnamed: C202.2, D202.1 (K), L201.1, U201.6 (SW)
unnamed: C202.1, U201.1 (CB)
unnamed: R202.2, R203.1, U201.3 (FB)
unnamed: R201.2, U201.4 (~SHDN)

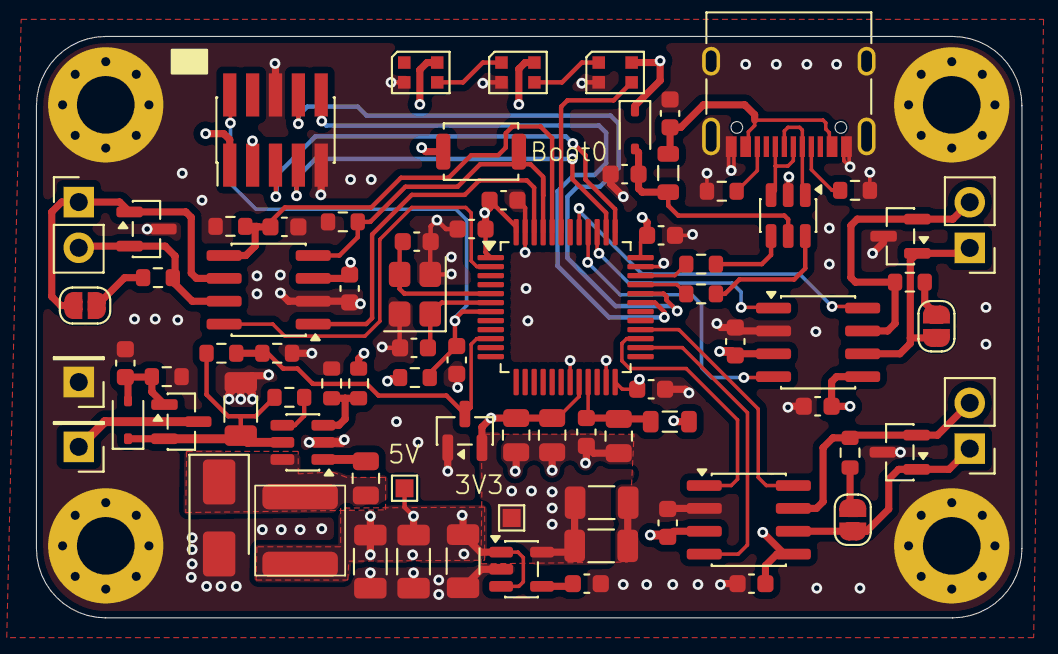
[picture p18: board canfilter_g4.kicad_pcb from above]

Board: 4 copper layers, 54.8 x 32.3 mm, 84 parts (1 on the bottom side), 52 nets.

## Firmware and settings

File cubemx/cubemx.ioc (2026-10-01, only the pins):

Mcu.UserName=STM32G474CBTx
PA10.Signal=USART1_RX
PA11.Signal=USB_DM
PA12.Signal=USB_DP
PA13.Signal=SYS_JTMS-SWDIO
PA14.Signal=SYS_JTCK-SWCLK
PA15.Signal=FDCAN3_TX
PA2.Signal=ADC1_IN3
PA9.Signal=USART1_TX
PB12.Signal=FDCAN2_RX
PB13.Signal=FDCAN2_TX
PB14.GPIO_Label=CAN2_S
PB14.Signal=GPIO_Output
PB3.Signal=FDCAN3_RX
PB4.GPIO_Label=CAN3_S
PB4.Signal=GPIO_Output
PB6.GPIO_Label=LED_CONTROL
PB6.Signal=S_TIM8_CH1
PB7.GPIO_Label=CAN1_S
PB7.Signal=GPIO_Output
PB8-BOOT0.Signal=FDCAN1_RX
PB9.Signal=FDCAN1_TX
PF0-OSC_IN.Signal=RCC_OSC_IN
PF1-OSC_OUT.Signal=RCC_OSC_OUT

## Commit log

2025-12-01 QR code
    [canfilter_g4-B_Cu.gbr, canfilter_g4-B_Mask.gbr, canfilter_g4-B_Paste.gbr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]
2026-10-01 Project update
    [can.kicad_sch, canfilter_g4.kicad_pcb, canfilter_g4.kicad_sch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]
